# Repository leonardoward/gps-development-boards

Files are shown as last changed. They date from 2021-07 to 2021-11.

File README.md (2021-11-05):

# GPS Development Board - ANTENOVA M20050-1 and ATGM332D-5N31 #

<p align="center">
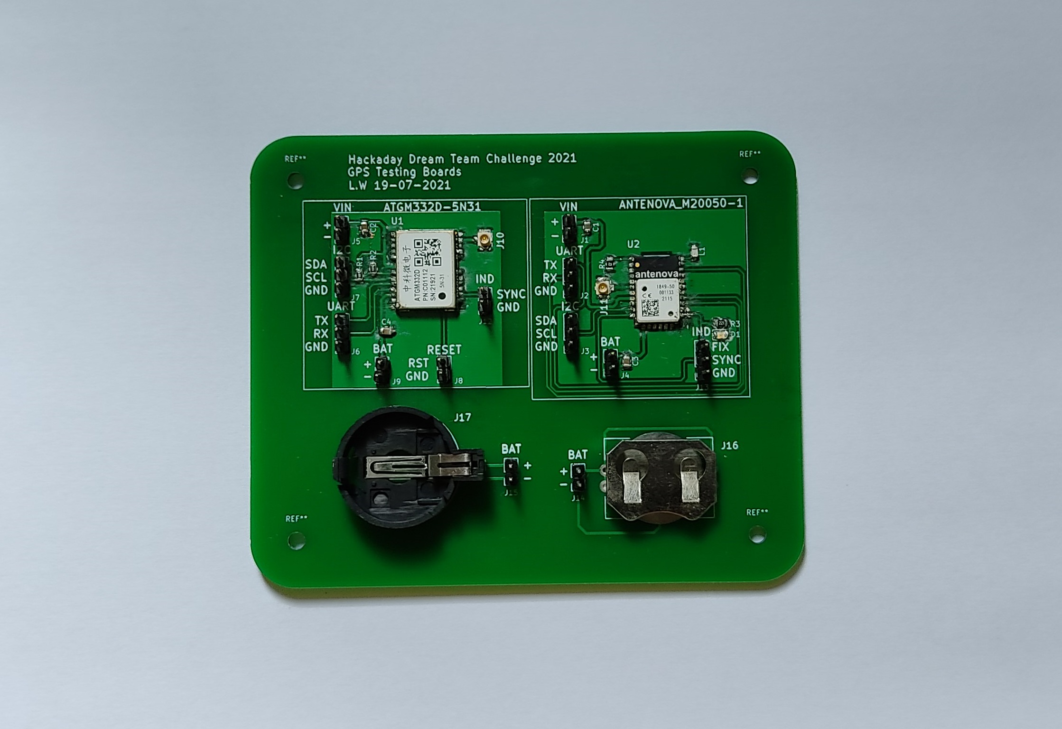
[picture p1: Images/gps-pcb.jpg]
  
</p>

This repository contains the design of a development board for the [ANTENOVA M20050-1](https://www.digikey.com/en/products/detail/antenova/M20050-1/7931495) and the [ATGM332D-5N31](https://lcsc.com/product-detail/Satellite-Positioning-Modules_ZHONGKEWEI-ATGM332D-5N31_C128659.html). The PCB was designed using KiCad.

## Schematic for the ANTENOVA M20050-1 ##

<p align="center">
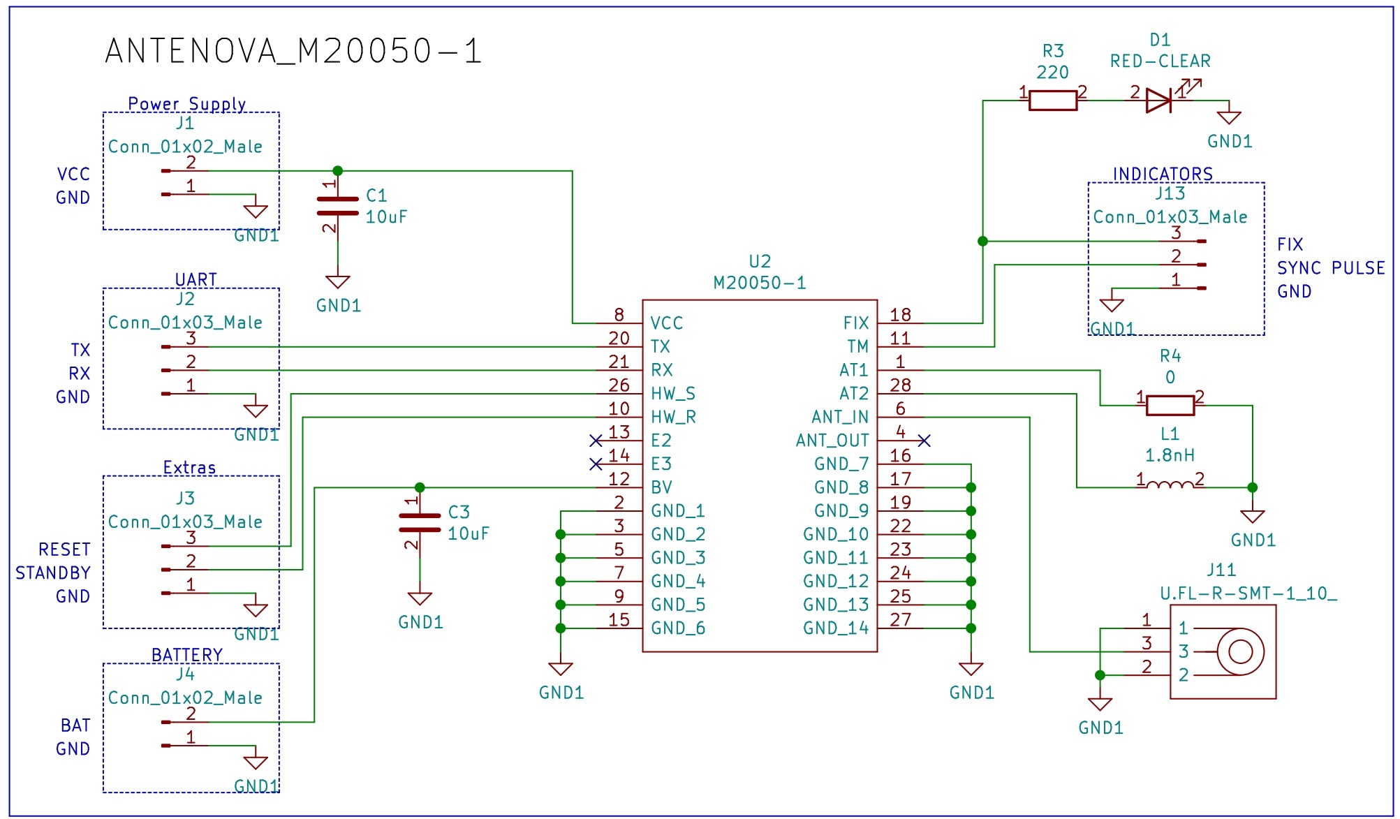
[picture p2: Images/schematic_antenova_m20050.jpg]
  
</p>

## Schematic for the ATGM332D-5N31 ##

<p align="center">
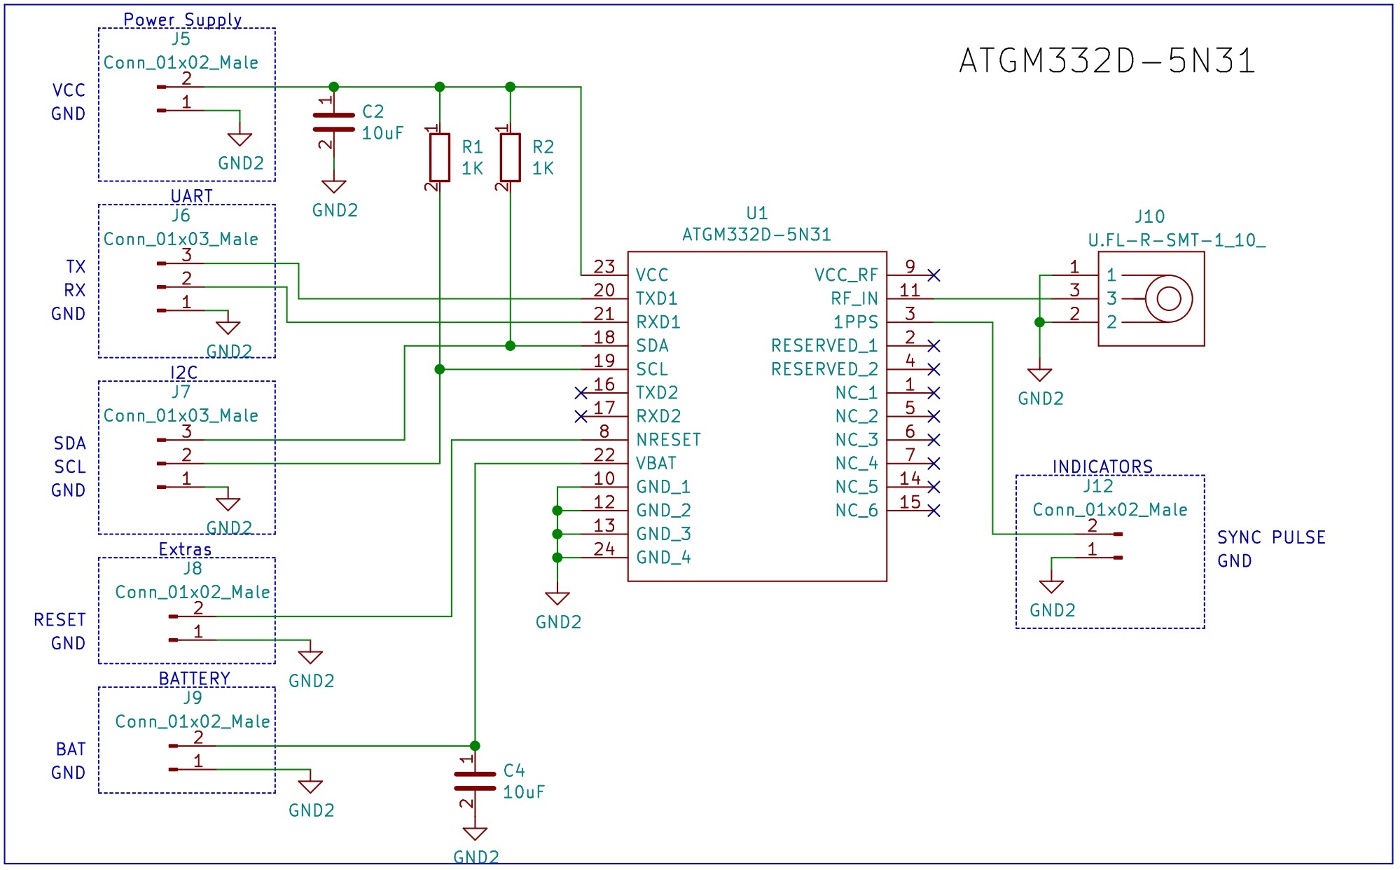
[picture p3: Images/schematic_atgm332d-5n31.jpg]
  
</p>

## Additional Coin Battery Holders ##

<p align="center">
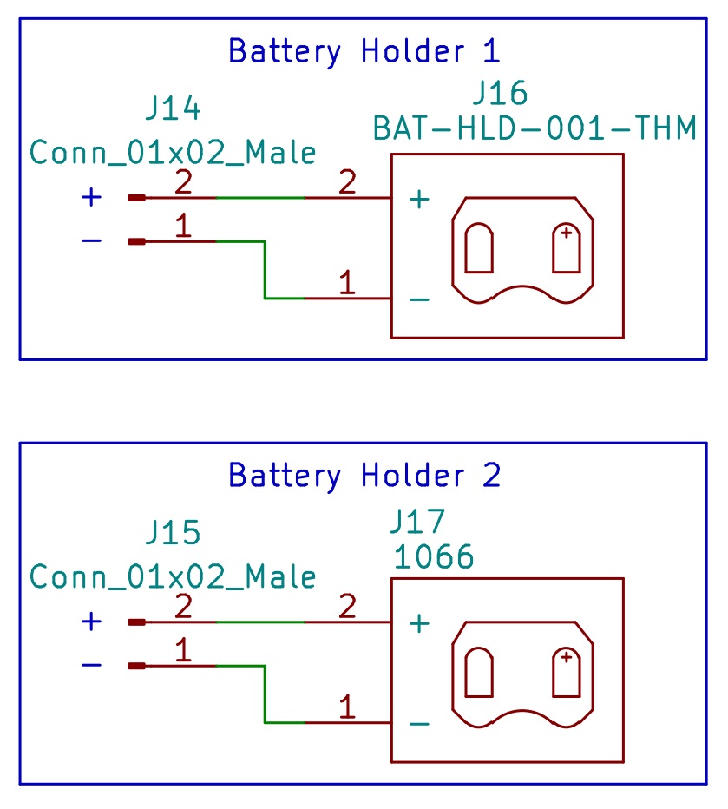
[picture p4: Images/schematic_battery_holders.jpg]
  
</p>

## Bill of Materials ##

| Reference | Quantity |
| --- | --- |
| [10 µF ±10% 6.3V Ceramic Capacitor X5R 0805 (2012 Metric)](https://www.digikey.com/en/products/detail/samsung-electro-mechanics/CL21A106KQCLNNC/3888062)  | 4 |
| [Red 630nm LED Indication - Discrete 1.9V 0805 (2012 Metric)](https://www.digikey.com/en/products/detail/w%C3%BCrth-elektronik/150080SS75000/4489921)  | 1 |
| [U.FL (UMCC) Connector Receptacle, Male Pin 50Ohm Surface Mount Solder](https://www.digikey.com/en/products/detail/hirose-electric-co-ltd/U-FL-R-SMT-1-10/2391570) | 2 |
| [Battery Retainer Coin, 20.0mm 1 Cell PC Pin](https://www.digikey.com/en/products/detail/linx-technologies-inc/BAT-HLD-001-THM/3044009) | 1 |
| [Battery Holder (Open) Coin, 20.0mm 1 Cell PC Pin](https://www.digikey.com/en/products/detail/keystone-electronics/1066/303562) | 1 |
| [Unshielded Multilayer Inductor 100mOhm Max 0805 (2012 Metric)](https://www.digikey.com/en/products/detail/abracon-llc/AIMC-0805-1N8S-T/2662915) | 1 |
| [1K ±1% 0.125W, 1/8W Chip Resistor 0805 (2012 Metric) Automotive AEC-Q200 Thick Film](https://www.digikey.com/en/products/detail/panasonic-electronic-components/ERJ-6ENF1001V/111281) | 2 |
| [220 Ohms ±5% 0.125W, 1/8W Chip Resistor 0805 (2012 Metric) Moisture Resistant Thick Film](https://www.digikey.com/en/products/detail/yageo/RC0805JR-07220RL/728283) | 1 |
| [0 Ohms Jumper 0.125W, 1/8W Chip Resistor 0805 (2012 Metric) Moisture Resistant Thick Film](https://www.digikey.com/en/products/detail/yageo/RC0805JR-070RL/728216) | 1 |
| [ATGM332D-5N31 GNSS Series GPS+BDS 12.2x16x2.4mm Satellite Positioning Modules ROHS](https://lcsc.com/product-detail/Satellite-Positioning-Modules_ZHONGKEWEI-ATGM332D-5N31_C128659.html) | 1 |
| [Antenova M20050-1 series RF Receiver GPS 1.575GHz -165dBm - On-Board, Trace Module](https://www.digikey.com/en/products/detail/antenova/M20050-1/7931495) | 1 |
| [Conn Header 40POS 2.54](https://www.digikey.com/en/products/detail/3m/2340-6111TG/1237275) | 1 |

## 3D Model ##

<p align="center">
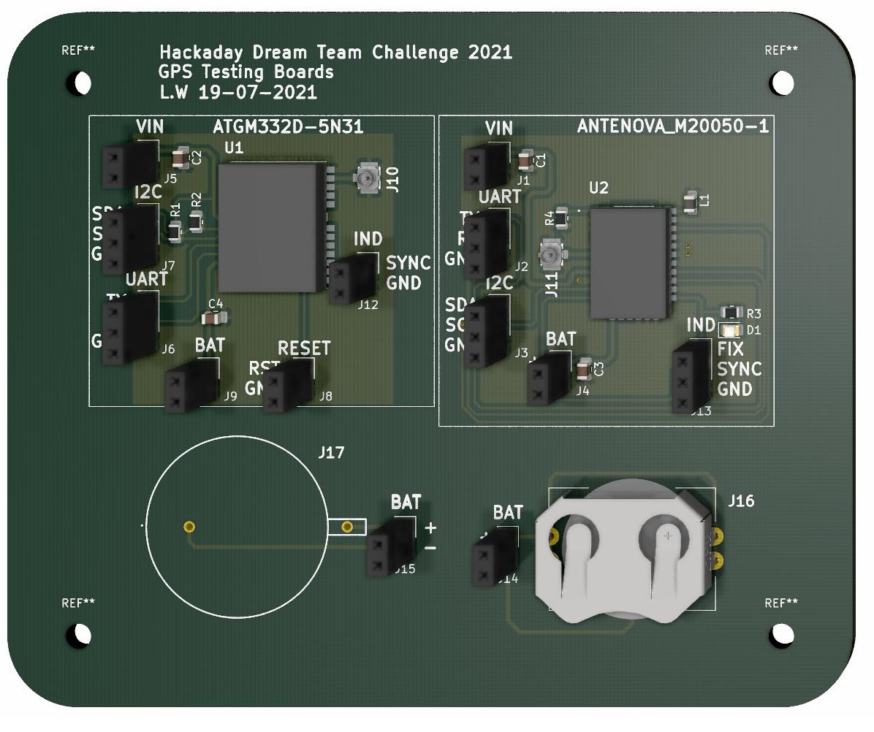
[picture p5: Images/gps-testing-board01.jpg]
  
</p>

<p align="center">
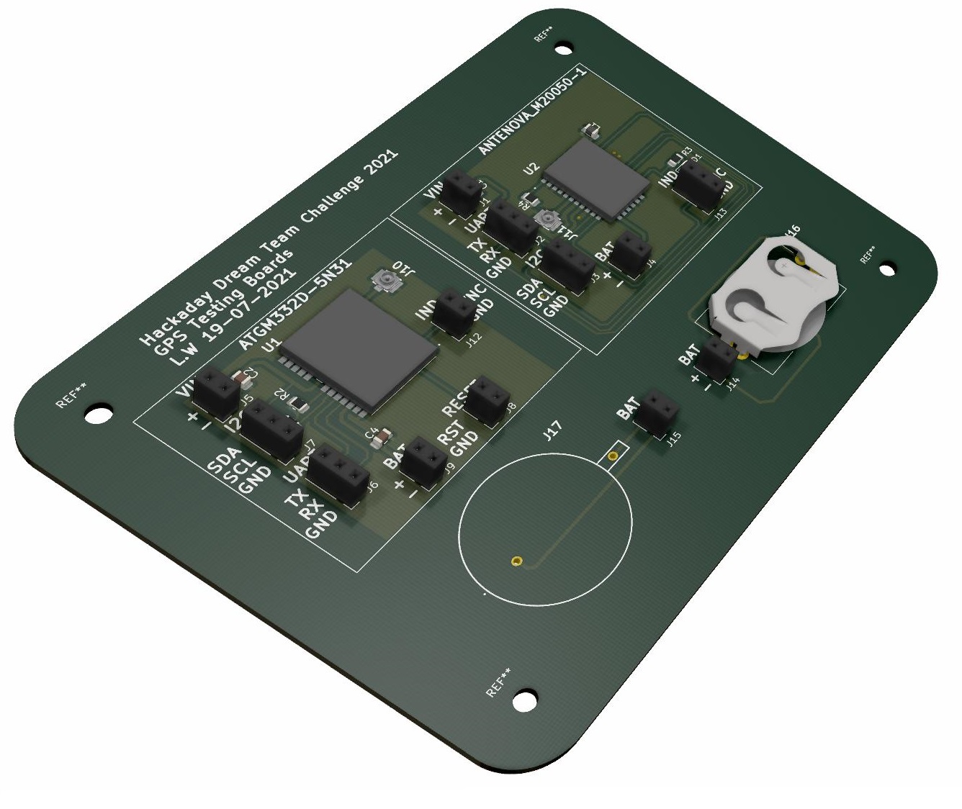
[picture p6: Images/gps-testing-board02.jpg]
  
</p>

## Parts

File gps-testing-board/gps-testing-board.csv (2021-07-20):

Source: | C:\Ext\gps-development-boards\gps-testing-board\gps-testing-board.sch
Date: | 7/19/2021 5:20:29 PM
Tool: | Eeschema (5.1.10)-1
Generator: | C:\Program Files\KiCad\bin\scripting\plugins/bom_csv_grouped_by_value.py
Component Count: | 29
Individual Components:
Item | Qty | Reference(s) | Value | LibPart | Footprint | Datasheet | Arrow Part Number | Arrow Price/Stock | Description | Height | LCSC | Manufacturer | Manufacturer Name | Manufacturer Part Number | Manufacturer_Name | Manufacturer_Part_Number | Mouser Part Number | Mouser Price/Stock | Supplier 1 | Supplier 2 | Supplier Part Number 1 | Supplier Part Number 2
 |  | C1 | 10uF | C-10uF-0805:10uF | Capacitor_SMD:C_0805_2012Metric |  |  |  |  |  |  | Samsung Electro-Mechanics |  | CL21A106KQCLNNC |  |  |  |  | Digi-Key |  | 1276-2404-1-ND
 |  | C2 | 10uF | C-10uF-0805:10uF | Capacitor_SMD:C_0805_2012Metric |  |  |  |  |  |  | Samsung Electro-Mechanics |  | CL21A106KQCLNNC |  |  |  |  | Digi-Key |  | 1276-2404-1-ND
 |  | C3 | 10uF | C-10uF-0805:10uF | Capacitor_SMD:C_0805_2012Metric |  |  |  |  |  |  | Samsung Electro-Mechanics |  | CL21A106KQCLNNC |  |  |  |  | Digi-Key |  | 1276-2404-1-ND
 |  | C4 | 10uF | C-10uF-0805:10uF | Capacitor_SMD:C_0805_2012Metric |  |  |  |  |  |  | Samsung Electro-Mechanics |  | CL21A106KQCLNNC |  |  |  |  | Digi-Key |  | 1276-2404-1-ND
 |  | D1 | RED-CLEAR | LED-RED-CLEAR-0805:RED-CLEAR | LED_SMD:LED_0805_2012Metric | https://www.we-online.de/katalog/datasheet/150080SS75000.pdf |  |  |  |  |  | Würth Elektronik |  | 150080SS75000 |  |  |  |  | Digi-Key |  | 732-4985-1-ND
 |  | J1 | Conn_01x02_Male | Connector:Conn_01x02_Male | Connector_PinSocket_2.54mm:PinSocket_1x02_P2.54mm_Vertical | ~
 |  | J2 | Conn_01x03_Male | Connector:Conn_01x03_Male | Connector_PinSocket_2.54mm:PinSocket_1x03_P2.54mm_Vertical | ~
 |  | J3 | Conn_01x03_Male | Connector:Conn_01x03_Male | Connector_PinSocket_2.54mm:PinSocket_1x03_P2.54mm_Vertical | ~
 |  | J4 | Conn_01x02_Male | Connector:Conn_01x02_Male | Connector_PinSocket_2.54mm:PinSocket_1x02_P2.54mm_Vertical | ~
 |  | J5 | Conn_01x02_Male | Connector:Conn_01x02_Male | Connector_PinSocket_2.54mm:PinSocket_1x02_P2.54mm_Vertical | ~
 |  | J6 | Conn_01x03_Male | Connector:Conn_01x03_Male | Connector_PinSocket_2.54mm:PinSocket_1x03_P2.54mm_Vertical | ~
 |  | J7 | Conn_01x03_Male | Connector:Conn_01x03_Male | Connector_PinSocket_2.54mm:PinSocket_1x03_P2.54mm_Vertical | ~
 |  | J8 | Conn_01x02_Male | Connector:Conn_01x02_Male | Connector_PinSocket_2.54mm:PinSocket_1x02_P2.54mm_Vertical | ~
 |  | J9 | Conn_01x02_Male | Connector:Conn_01x02_Male | Connector_PinSocket_2.54mm:PinSocket_1x02_P2.54mm_Vertical | ~
 |  | J10 | U.FL-R-SMT-1_10_ | U.FL-R-SMT-1_10_:U.FL-R-SMT-1_10_ | U.FL-R-SMT-1(10):U.FL-R-SMT-1_10_ | https://www.hirose.com/product/document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 | U.FL-R-SMT-1(10) | https://www.arrow.com/en/products/u.fl-r-smt-1-10/hirose-electric | UFL SMT PCB receptable,DC-6GHz Hirose Straight 50 Surface Mount UFL Connector, Receptacle, Solder Termination Coaxial |  |  |  | Hirose | U.FL-R-SMT-1(10) | Hirose | U.FL-R-SMT-1(10) | 798-U.FL-R-SMT-110 | https://www.mouser.co.uk/ProductDetail/Hirose-Connector/UFL-R-SMT-110?qs=kL1ClTr6oBoOdtqlGQpQrQ%3D%3D | Digi-Key | Mouser | H11891CT-ND | 798-U.FL-R-SMT-110
 |  | J11 | U.FL-R-SMT-1_10_ | U.FL-R-SMT-1_10_:U.FL-R-SMT-1_10_ | U.FL-R-SMT-1(10):U.FL-R-SMT-1_10_ | https://www.hirose.com/product/document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 | U.FL-R-SMT-1(10) | https://www.arrow.com/en/products/u.fl-r-smt-1-10/hirose-electric | UFL SMT PCB receptable,DC-6GHz Hirose Straight 50 Surface Mount UFL Connector, Receptacle, Solder Termination Coaxial |  |  |  | Hirose | U.FL-R-SMT-1(10) | Hirose | U.FL-R-SMT-1(10) | 798-U.FL-R-SMT-110 | https://www.mouser.co.uk/ProductDetail/Hirose-Connector/UFL-R-SMT-110?qs=kL1ClTr6oBoOdtqlGQpQrQ%3D%3D | Digi-Key | Mouser | H11891CT-ND | 798-U.FL-R-SMT-110
 |  | J12 | Conn_01x02_Male | Connector:Conn_01x02_Male | Connector_PinSocket_2.54mm:PinSocket_1x02_P2.54mm_Vertical | ~
 |  | J13 | Conn_01x03_Male | Connector:Conn_01x03_Male | Connector_PinSocket_2.54mm:PinSocket_1x03_P2.54mm_Vertical | ~
 |  | J14 | Conn_01x02_Male | Connector:Conn_01x02_Male | Connector_PinSocket_2.54mm:PinSocket_1x02_P2.54mm_Vertical | ~
 |  | J15 | Conn_01x02_Male | Connector:Conn_01x02_Male | Connector_PinSocket_2.54mm:PinSocket_1x02_P2.54mm_Vertical | ~
 |  | J16 | BAT-HLD-001-THM | BAT-HLD-001-THM:BAT-HLD-001-THM | BAT-HLD-001-THM:BATHLD001THM | http://www.mouser.com/datasheet/2/238/BAT-HLD-001-THM Diagram-1175214.pdf |  |  | Coin Cell Battery Holders Bat Hld CR2032/2025 Through-hole Mount | 4.2 |  |  |  |  | Linx Technologies | BAT-HLD-001-THM |  |  | Digi-Key | Mouser | BAT-HLD-001-THM-ND | 712-BAT-HLD-001-THM
 |  | J17 | 1066 | BAT-1066:1066 | BAT-1066:BAT-1066 | http://keyelco.com/userAssets/file/M65p5.pdf |  |  | KEYSTONE - 1066.. - Battery Holder, Coin Cell - 20mm x 1, Through Hole | 9.85 |  |  |  |  | Keystone Electronics | 1066 |  |  | Digi-Key | Mouser | 36-1066-ND | 534-1066
 |  | L1 | 1.8nH | L-1.8nH-0805:1.8nH | Inductor_SMD:L_0805_2012Metric | https://abracon.com/Magnetics/new/AIMC-0805.pdf |  |  |  |  |  | Abracon LLC |  | AIMC-0805-1N8S-T |  |  |  |  | Digi-Key |  | 535-11559-1-ND
 |  | R1 | 1K | R-1K-0805:1K | Resistor_SMD:R_0805_2012Metric | https://industrial.panasonic.com/cdbs/www-data/pdf/RDA0000/AOA0000C304.pdf |  |  |  |  |  | Panasonic Electronic Components |  | ERJ-6ENF1001V |  |  |  |  | Digi-Key |  | P1.00KCCT-ND
 |  | R2 | 1K | R-1K-0805:1K | Resistor_SMD:R_0805_2012Metric | https://industrial.panasonic.com/cdbs/www-data/pdf/RDA0000/AOA0000C304.pdf |  |  |  |  |  | Panasonic Electronic Components |  | ERJ-6ENF1001V |  |  |  |  | Digi-Key |  | P1.00KCCT-ND
 |  | R3 | 220 | R-220-0805:220 | Resistor_SMD:R_0805_2012Metric | https://www.yageo.com/upload/media/product/productsearch/datasheet/rchip/PYu-RC_Group_51_RoHS_L_11.pdf |  |  |  |  |  | Yageo |  | RC0805JR-07220RL |  |  |  |  | Digi-Key |  | 311-220ARCT-ND
 |  | R4 | 0 | R-0-0805:0 | Resistor_SMD:R_0805_2012Metric | https://www.yageo.com/upload/media/product/productsearch/datasheet/rchip/PYu-RC_Group_51_RoHS_L_11.pdf |  |  |  |  |  | Yageo |  | RC0805JR-070RL |  |  |  |  | Digi-Key |  | 311-0.0ARCT-ND
 |  | U1 | ATGM332D-5N31 | ATGM332D-5N31:ATGM332D-5N31 | ATGM332D-5N31:ATGM332D5N31 | https://datasheet.lcsc.com/szlcsc/ZHONGKEWEI-ATGM332D-5N31_C128659.pdf |  |  | Communication Modules/GNSS Modules 12.2x16x2.4mm | 2.6 | C128659 |  |  |  | ZHONGKEWEI | ATGM332D-5N31
 |  | U2 | M20050-1 | M20050-1:M20050-1 | M20050-1:M200501 | https://www.mouser.com/datasheet/2/23/antenova_M20050-1-1279284.pdf |  |  | Antennas GPS/GNSS RADIONOVA RF Module MTK chipset | 2 |  |  |  |  | Antenova | M20050-1 |  |  | Digi-Key | Mouser | 627-1100-1-ND | 237-M20050-1
Collated Components:
Item | Qty | Reference(s) | Value | LibPart | Footprint | Datasheet | Arrow Part Number | Arrow Price/Stock | Description | Height | LCSC | Manufacturer | Manufacturer Name | Manufacturer Part Number | Manufacturer_Name | Manufacturer_Part_Number | Mouser Part Number | Mouser Price/Stock | Supplier 1 | Supplier 2 | Supplier Part Number 1 | Supplier Part Number 2
1 | 4 | C1, C2, C3, C4 | 10uF | C-10uF-0805:10uF | Capacitor_SMD:C_0805_2012Metric |  |  |  |  |  |  | Samsung Electro-Mechanics |  | CL21A106KQCLNNC |  |  |  |  | Digi-Key |  | 1276-2404-1-ND
2 | 1 | D1 | RED-CLEAR | LED-RED-CLEAR-0805:RED-CLEAR | LED_SMD:LED_0805_2012Metric | https://www.we-online.de/katalog/datasheet/150080SS75000.pdf |  |  |  |  |  | Würth Elektronik |  | 150080SS75000 |  |  |  |  | Digi-Key |  | 732-4985-1-ND
3 | 8 | J1, J4, J5, J8, J9, J12, J14, J15 | Conn_01x02_Male | Connector:Conn_01x02_Male | Connector_PinSocket_2.54mm:PinSocket_1x02_P2.54mm_Vertical | ~
4 | 5 | J2, J3, J6, J7, J13 | Conn_01x03_Male | Connector:Conn_01x03_Male | Connector_PinSocket_2.54mm:PinSocket_1x03_P2.54mm_Vertical | ~
5 | 2 | J10, J11 | U.FL-R-SMT-1_10_ | U.FL-R-SMT-1_10_:U.FL-R-SMT-1_10_ | U.FL-R-SMT-1(10):U.FL-R-SMT-1_10_ | https://www.hirose.com/product/document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 | U.FL-R-SMT-1(10) | https://www.arrow.com/en/products/u.fl-r-smt-1-10/hirose-electric | UFL SMT PCB receptable,DC-6GHz Hirose Straight 50 Surface Mount UFL Connector, Receptacle, Solder Termination Coaxial |  |  |  | Hirose | U.FL-R-SMT-1(10) | Hirose | U.FL-R-SMT-1(10) | 798-U.FL-R-SMT-110 | https://www.mouser.co.uk/ProductDetail/Hirose-Connector/UFL-R-SMT-110?qs=kL1ClTr6oBoOdtqlGQpQrQ%3D%3D | Digi-Key | Mouser | H11891CT-ND | 798-U.FL-R-SMT-110
6 | 1 | J16 | BAT-HLD-001-THM | BAT-HLD-001-THM:BAT-HLD-001-THM | BAT-HLD-001-THM:BATHLD001THM | http://www.mouser.com/datasheet/2/238/BAT-HLD-001-THM Diagram-1175214.pdf |  |  | Coin Cell Battery Holders Bat Hld CR2032/2025 Through-hole Mount | 4.2 |  |  |  |  | Linx Technologies | BAT-HLD-001-THM |  |  | Digi-Key | Mouser | BAT-HLD-001-THM-ND | 712-BAT-HLD-001-THM
7 | 1 | J17 | 1066 | BAT-1066:1066 | BAT-1066:BAT-1066 | http://keyelco.com/userAssets/file/M65p5.pdf |  |  | KEYSTONE - 1066.. - Battery Holder, Coin Cell - 20mm x 1, Through Hole | 9.85 |  |  |  |  | Keystone Electronics | 1066 |  |  | Digi-Key | Mouser | 36-1066-ND | 534-1066
8 | 1 | L1 | 1.8nH | L-1.8nH-0805:1.8nH | Inductor_SMD:L_0805_2012Metric | https://abracon.com/Magnetics/new/AIMC-0805.pdf |  |  |  |  |  | Abracon LLC |  | AIMC-0805-1N8S-T |  |  |  |  | Digi-Key |  | 535-11559-1-ND
9 | 2 | R1, R2 | 1K | R-1K-0805:1K | Resistor_SMD:R_0805_2012Metric | https://industrial.panasonic.com/cdbs/www-data/pdf/RDA0000/AOA0000C304.pdf |  |  |  |  |  | Panasonic Electronic Components |  | ERJ-6ENF1001V |  |  |  |  | Digi-Key |  | P1.00KCCT-ND
10 | 1 | R3 | 220 | R-220-0805:220 | Resistor_SMD:R_0805_2012Metric | https://www.yageo.com/upload/media/product/productsearch/datasheet/rchip/PYu-RC_Group_51_RoHS_L_11.pdf |  |  |  |  |  | Yageo |  | RC0805JR-07220RL |  |  |  |  | Digi-Key |  | 311-220ARCT-ND
11 | 1 | R4 | 0 | R-0-0805:0 | Resistor_SMD:R_0805_2012Metric | https://www.yageo.com/upload/media/product/productsearch/datasheet/rchip/PYu-RC_Group_51_RoHS_L_11.pdf |  |  |  |  |  | Yageo |  | RC0805JR-070RL |  |  |  |  | Digi-Key |  | 311-0.0ARCT-ND
12 | 1 | U1 | ATGM332D-5N31 | ATGM332D-5N31:ATGM332D-5N31 | ATGM332D-5N31:ATGM332D5N31 | https://datasheet.lcsc.com/szlcsc/ZHONGKEWEI-ATGM332D-5N31_C128659.pdf |  |  | Communication Modules/GNSS Modules 12.2x16x2.4mm | 2.6 | C128659 |  |  |  | ZHONGKEWEI | ATGM332D-5N31
13 | 1 | U2 | M20050-1 | M20050-1:M20050-1 | M20050-1:M200501 | https://www.mouser.com/datasheet/2/23/antenova_M20050-1-1279284.pdf |  |  | Antennas GPS/GNSS RADIONOVA RF Module MTK chipset | 2 |  |  |  |  | Antenova | M20050-1 |  |  | Digi-Key | Mouser | 627-1100-1-ND | 237-M20050-1

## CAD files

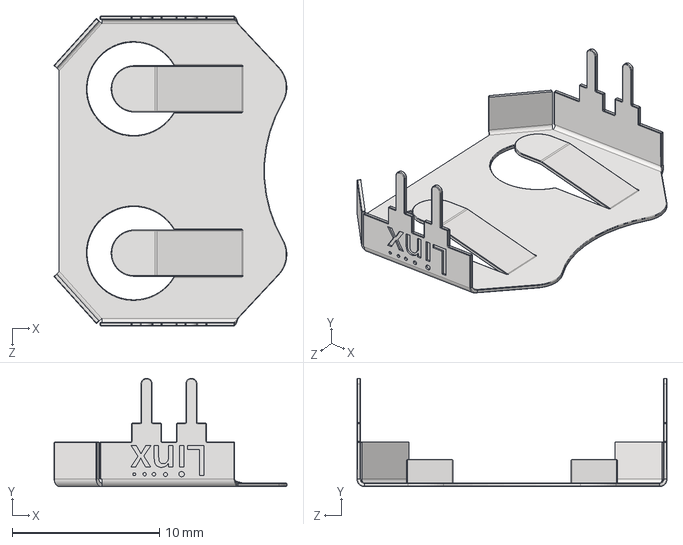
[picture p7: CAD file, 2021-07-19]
gps-testing-board/3D/BAT-HLD-001-THM.stp
15.8 x 7.37 x 21.1 mm

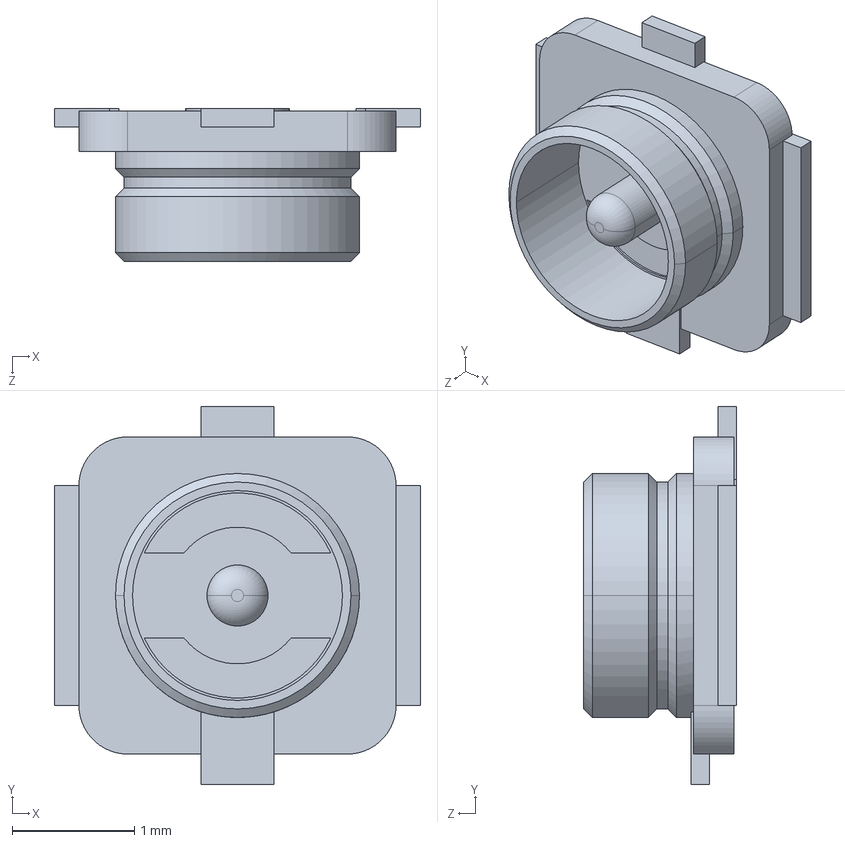
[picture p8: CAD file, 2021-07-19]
gps-testing-board/3D/U.FL-R-SMT-1_10_.stp
3.00 x 3.10 x 1.25 mm

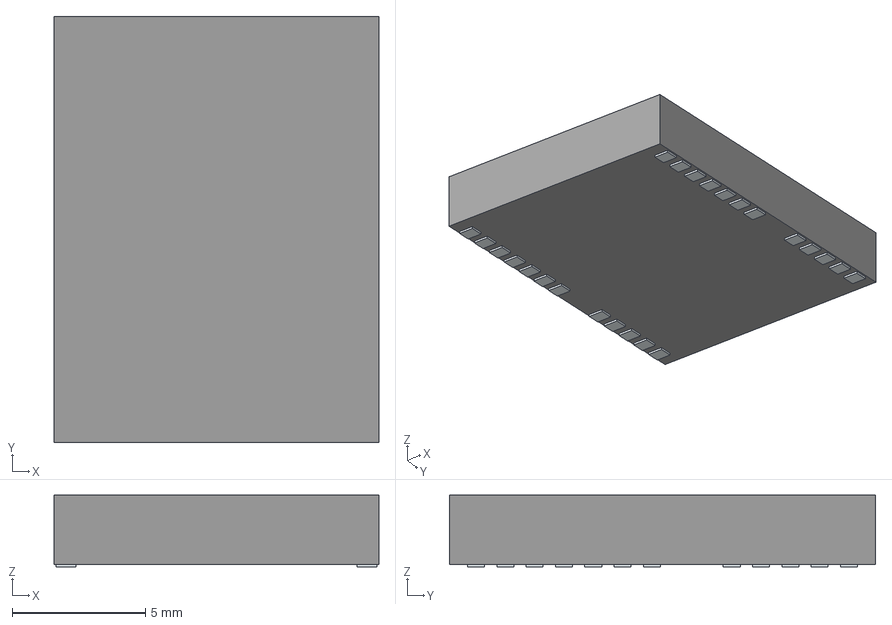
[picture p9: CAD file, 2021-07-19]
gps-testing-board/3D/ATGM332D-5N31.stp
12.2 x 16.0 x 2.70 mm
Pins

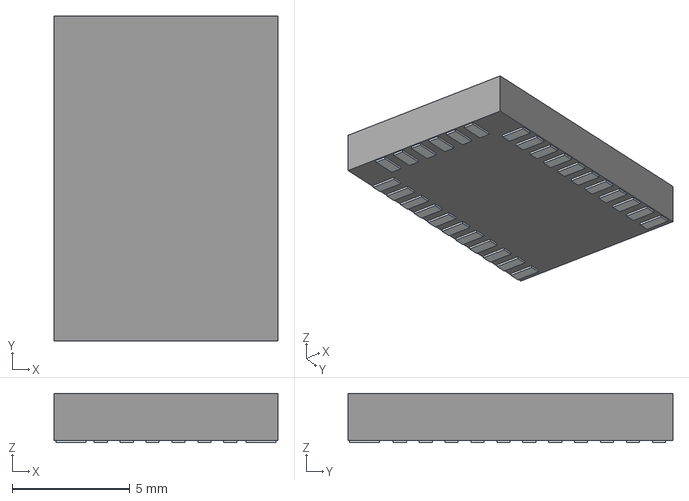
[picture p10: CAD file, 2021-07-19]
gps-testing-board/3D/M20050-1.stp
9.50 x 13.8 x 2.10 mm
Pins

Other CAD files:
gps-testing-board/3D/ATGM332D-5N31.stl
gps-testing-board/3D/M20050-1.stl

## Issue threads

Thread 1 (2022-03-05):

No GPS FIX

josullivan31, 2022-03-05:
Hello, using this schematic I was unable to get a GPS Fix. it would occasionally detect 2-7 GPS satellites but never long enough to get a fix. Would you be able to provide any insight as to why this is?

Thank you,

Jack

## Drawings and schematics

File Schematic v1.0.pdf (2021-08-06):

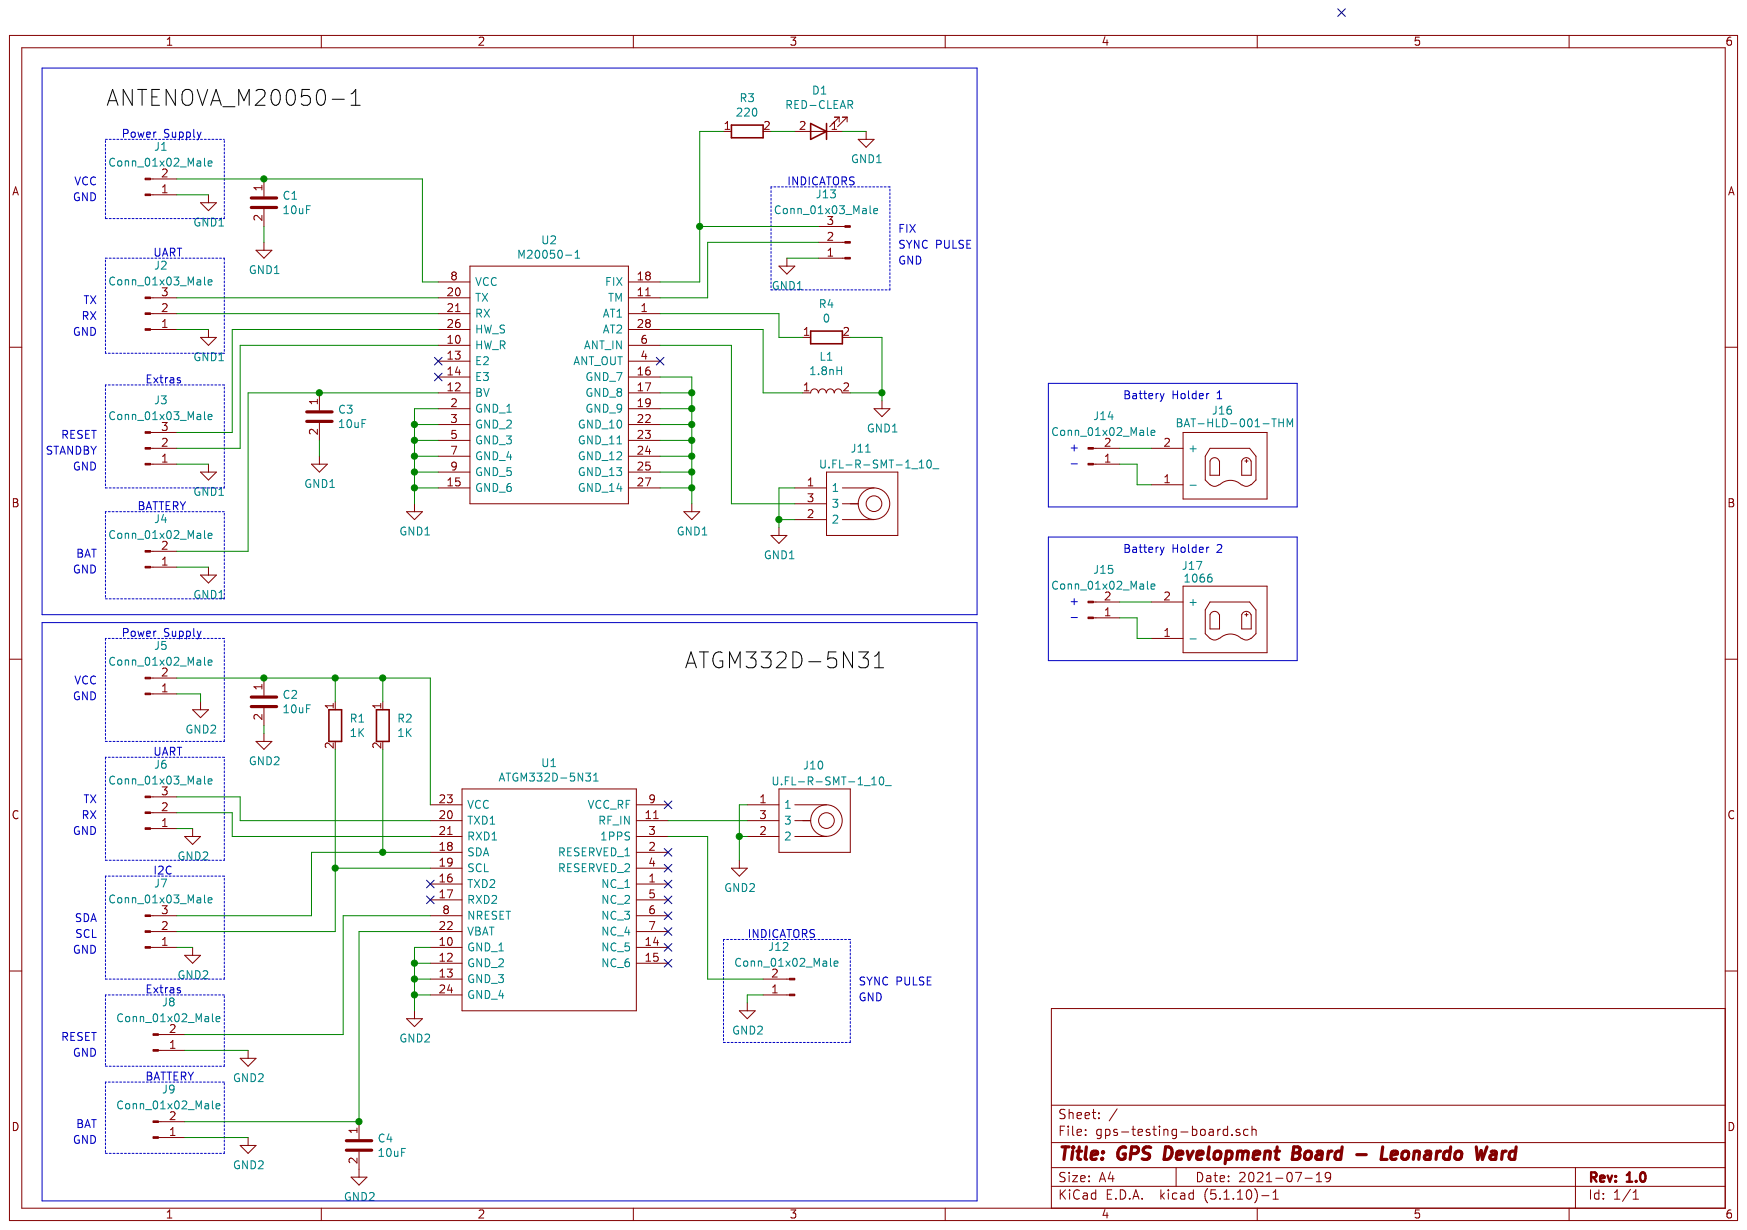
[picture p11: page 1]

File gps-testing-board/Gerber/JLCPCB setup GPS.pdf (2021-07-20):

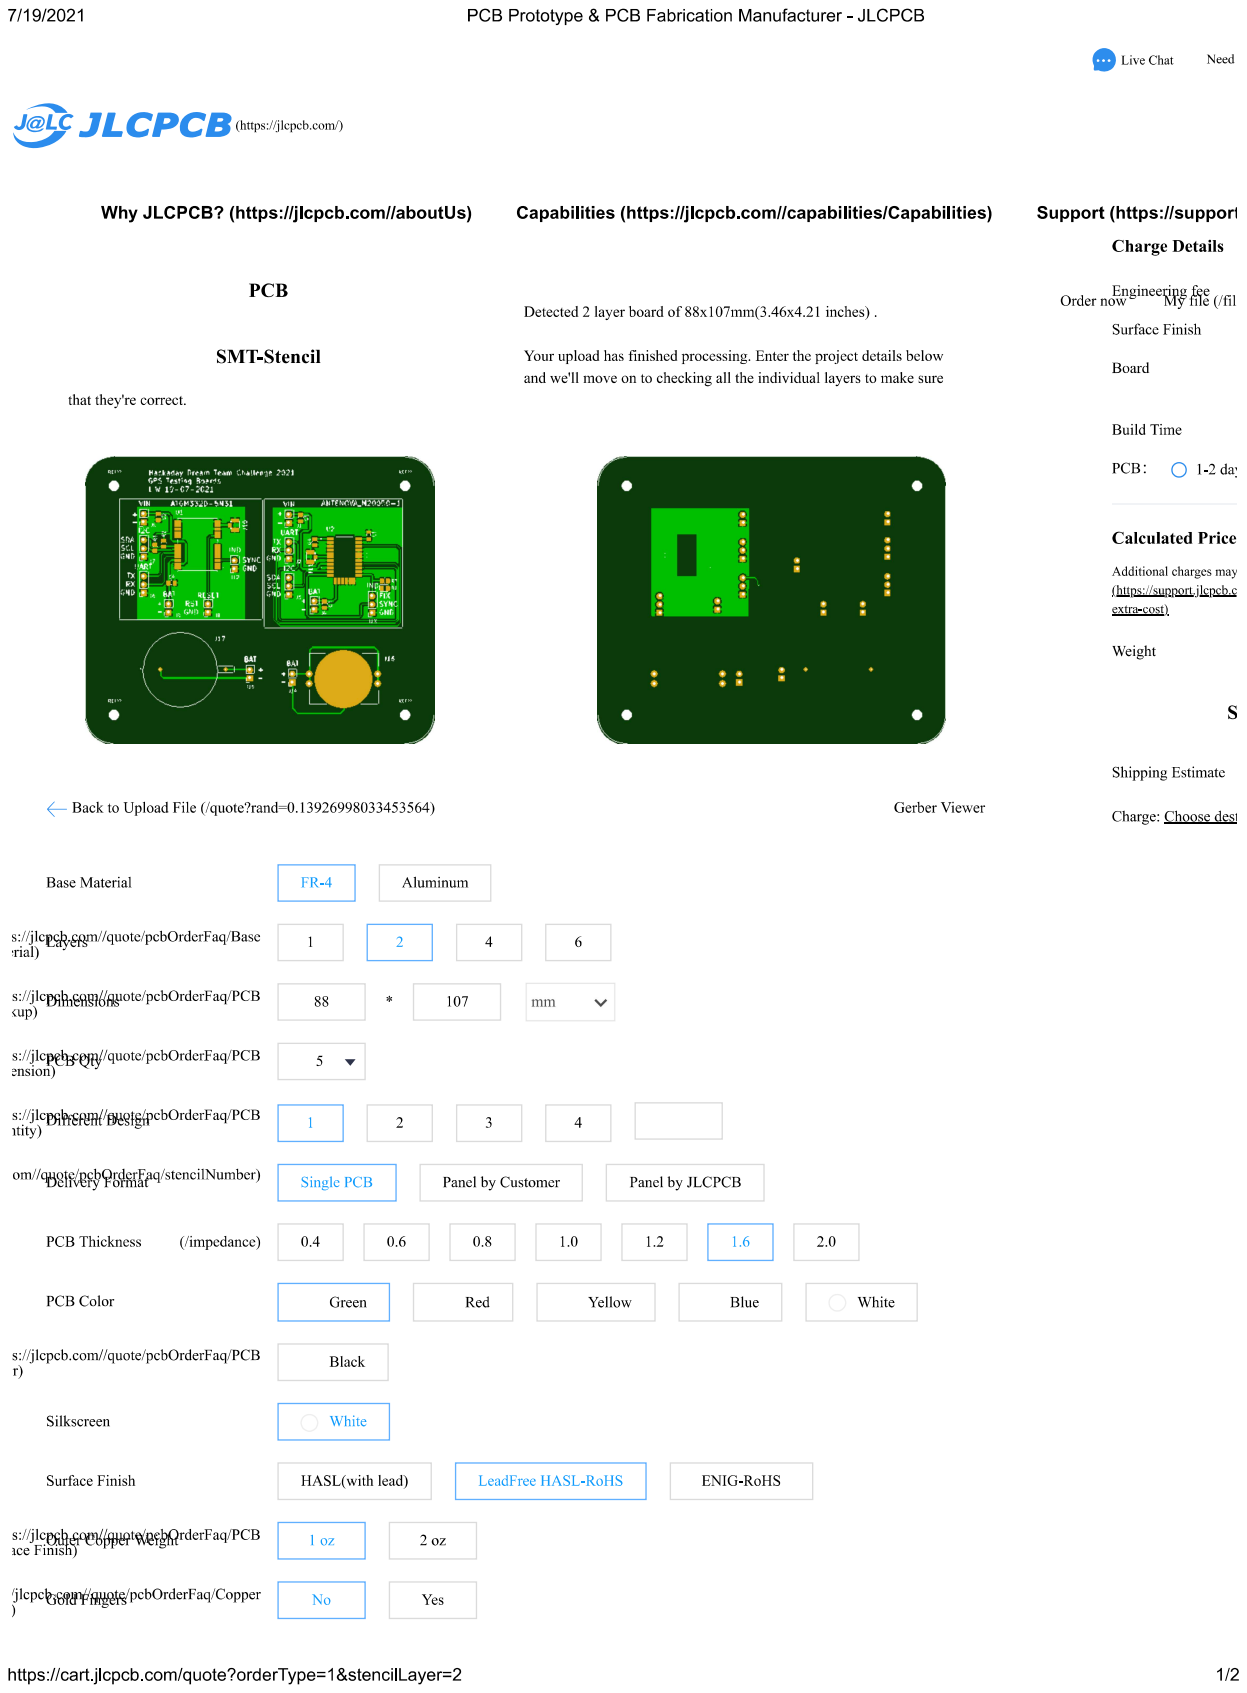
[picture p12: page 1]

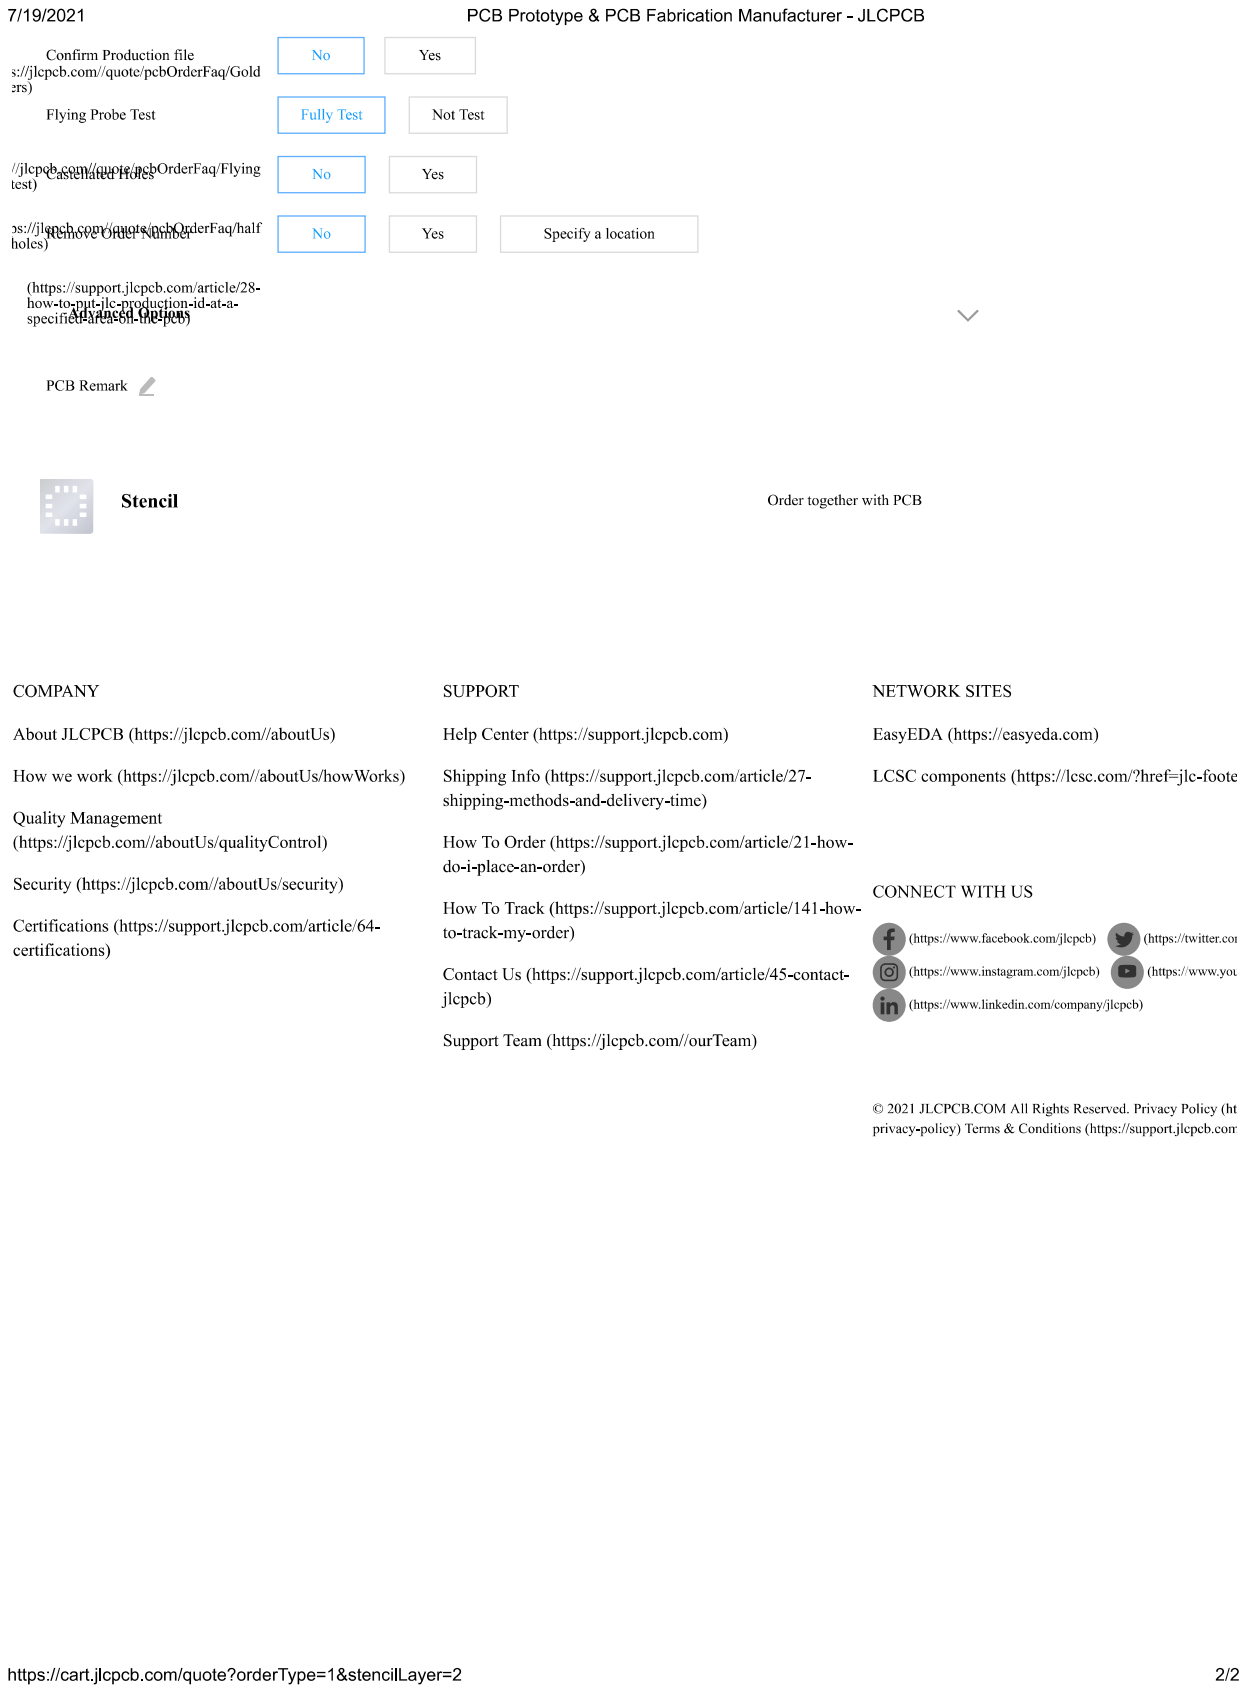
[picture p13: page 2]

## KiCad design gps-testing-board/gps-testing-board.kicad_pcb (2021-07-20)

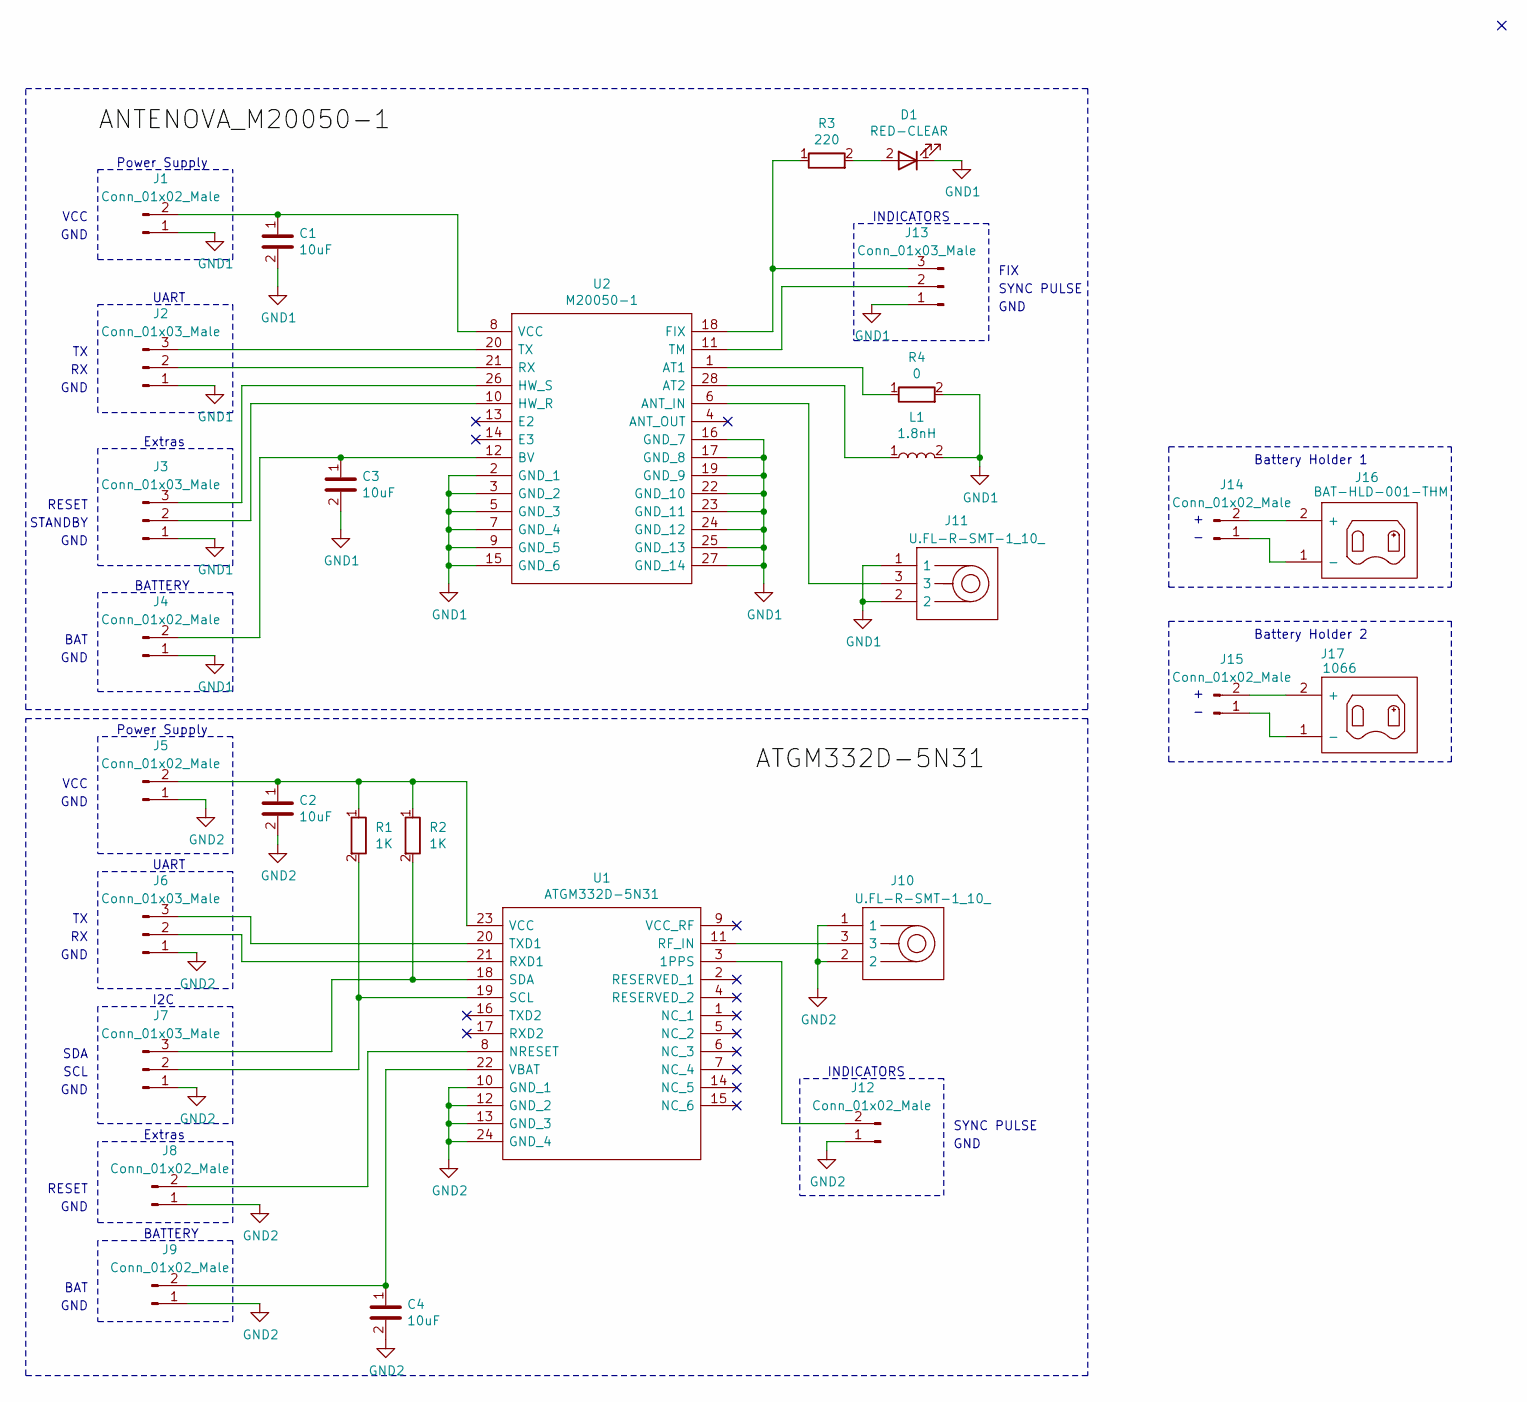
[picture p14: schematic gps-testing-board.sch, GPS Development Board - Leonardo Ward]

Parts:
C1, C2, C3, C4: 10uF; C_0805_2012Metric; Manufacturer Part Number CL21A106KQCLNNC
D1: RED-CLEAR; LED_0805_2012Metric; Manufacturer Part Number 150080SS75000
J1, J4, J5, J8, J9, J12, J14, J15: Conn_01x02_Male; PinSocket_1x02_P2.54mm_Vertical
J2, J3, J6, J7, J13: Conn_01x03_Male; PinSocket_1x03_P2.54mm_Vertical
J10, J11: U.FL-R-SMT-1_10_; Manufacturer_Part_Number U.FL-R-SMT-1(10); Mouser Part Number 798-U.FL-R-SMT-110
J16: BAT-HLD-001-THM; BATHLD001THM; Manufacturer_Part_Number BAT-HLD-001-THM
J17: 1066; BAT-1066; Manufacturer_Part_Number 1066
L1: 1.8nH; L_0805_2012Metric; Manufacturer Part Number AIMC-0805-1N8S-T
R1, R2: 1K; R_0805_2012Metric; Manufacturer Part Number ERJ-6ENF1001V
R3: 220; R_0805_2012Metric; Manufacturer Part Number RC0805JR-07220RL
R4: 0; R_0805_2012Metric; Manufacturer Part Number RC0805JR-070RL
U1: ATGM332D-5N31; ATGM332D5N31; Manufacturer_Part_Number ATGM332D-5N31; LCSC C128659
U2: M20050-1; M200501; Manufacturer_Part_Number M20050-1

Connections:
GND1: C1.2, C3.2, D1.1 (K), J1.1, J2.1, J3.1, J4.1, J11.1, J11.2, J13.1, L1.2, R4.2, U2.2 (GND_1), U2.3 (GND_2), U2.5 (GND_3), U2.7 (GND_4), U2.9 (GND_5), U2.15 (GND_6), U2.16 (GND_7), U2.17 (GND_8), U2.19 (GND_9), U2.22 (GND_10), U2.23 (GND_11), U2.24 (GND_12), U2.25 (GND_13), U2.27 (GND_14)
GND2: C2.2, C4.2, J5.1, J6.1, J7.1, J8.1, J9.1, J10.1, J10.2, J12.1, U1.10 (GND_1), U1.12 (GND_2), U1.13 (GND_3), U1.24 (GND_4)
unnamed: C1.1, J1.2, U2.8 (VCC)
unnamed: C2.1, J5.2, R1.1, R2.1, U1.23 (VCC)
unnamed: C3.1, J4.2, U2.12 (BV)
unnamed: C4.1, J9.2, U1.22 (VBAT)
unnamed: D1.2 (A), R3.2
unnamed: J2.2, U2.21 (RX)
unnamed: J2.3, U2.20 (TX)
unnamed: J3.2, U2.10 (HW_R)
unnamed: J3.3, U2.26 (HW_S)
unnamed: J6.2, U1.21 (RXD1)
unnamed: J6.3, U1.20 (TXD1)
unnamed: J7.2, R1.2, U1.19 (SCL)
unnamed: J7.3, R2.2, U1.18 (SDA)
unnamed: J8.2, U1.8 (NRESET)
unnamed: J10.3, U1.11 (RF_IN)
unnamed: J11.3, U2.6 (ANT_IN)
unnamed: J12.2, U1.3 (1PPS)
unnamed: J13.2, U2.11 (TM)
unnamed: J13.3, R3.1, U2.18 (FIX)
unnamed: J14.1, J16.1 (-)
unnamed: J14.2, J16.2 (+)
unnamed: J15.1, J17.1 (-)
unnamed: J15.2, J17.2 (+)
unnamed: L1.1, U2.28 (AT2)
unnamed: R4.1, U2.1 (AT1)

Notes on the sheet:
VCC
GND
UART
Power Supply
Extras
RESET
STANDBY
BATTERY
BAT
INDICATORS
FIX
SYNC PULSE
SDA
SCL
I2C
Battery Holder 1
Battery Holder 2

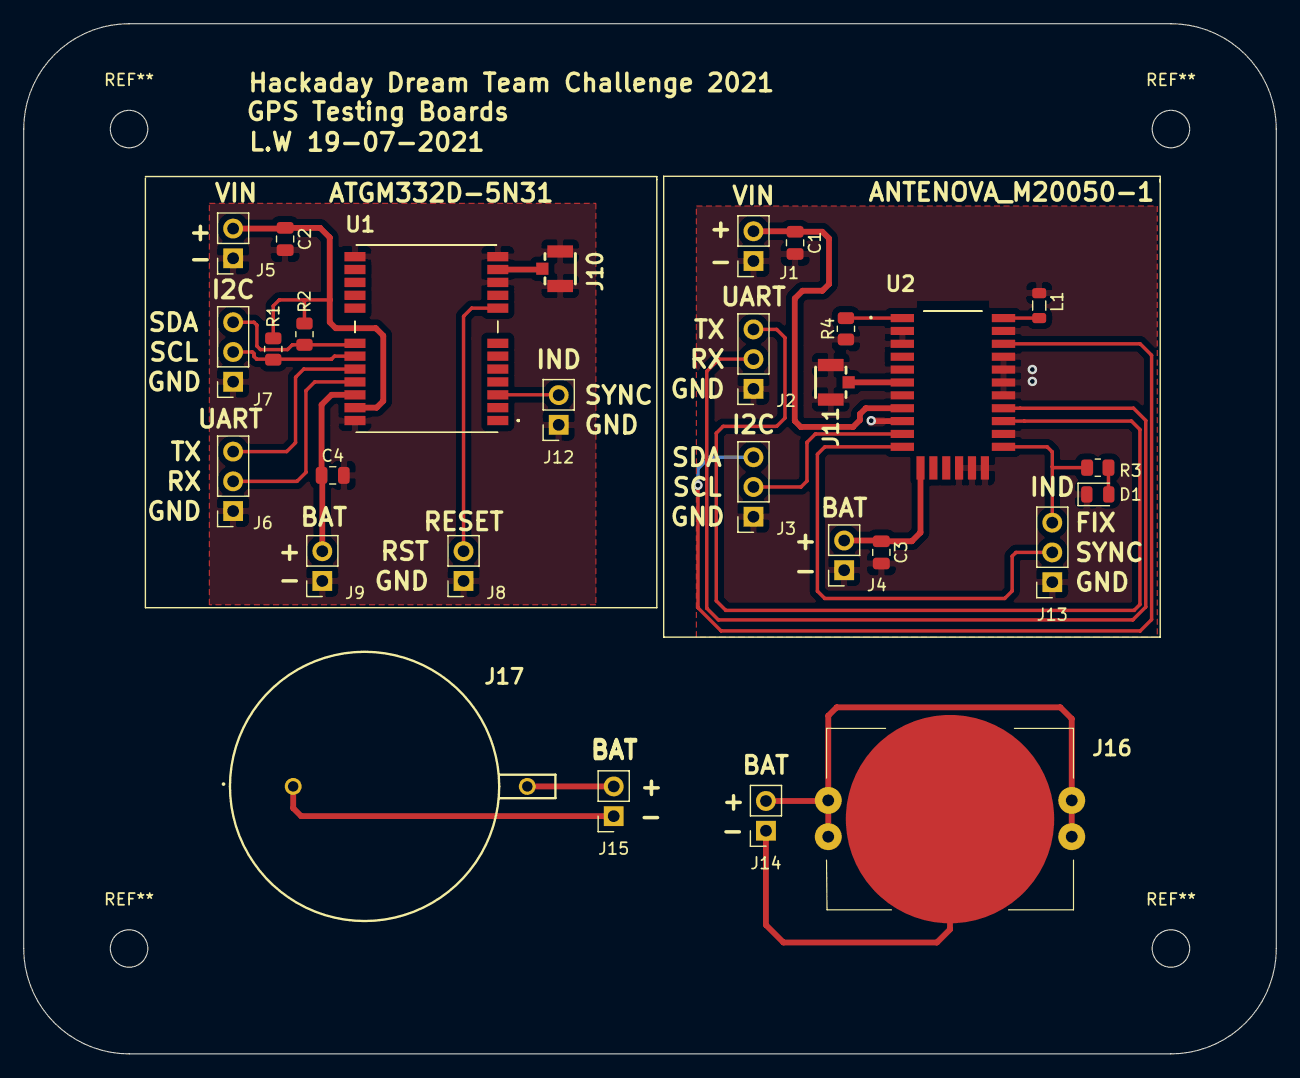
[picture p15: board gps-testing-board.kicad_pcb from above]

Board: 2 copper layers, 107.0 x 88.0 mm, 29 parts (0 on the bottom side), 27 nets.

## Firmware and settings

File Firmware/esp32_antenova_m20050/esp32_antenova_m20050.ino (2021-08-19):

//#include <NeoSWSerial.h>
#include <FuGPS.h>

#define RXD2 16
#define TXD2 17

//NeoSWSerial in(8, 9);
FuGPS fuGPS(Serial2);

bool gpsAlive = false;

void setup() {
   Serial.begin(115200);
   Serial.println("Antenova M20050");
   //in.begin(9600);
   Serial2.begin(9600, SERIAL_8N1, RXD2, TXD2);
   // fuGPS.sendCommand(FUGPS_PMTK_SET_NMEA_BAUDRATE_9600);
   // fuGPS.sendCommand(FUGPS_PMTK_SET_NMEA_UPDATERATE_1HZ);
   fuGPS.sendCommand(FUGPS_PMTK_API_SET_NMEA_OUTPUT_RMCGGA);
}
  
void loop() {
   // Valid NMEA message

   if (fuGPS.read())
   {
       byte tokenIdx = 0;
       while (const char * token = fuGPS.getField(tokenIdx++))
       {
           Serial.print("Token [" + String(tokenIdx) + "]: ");
           Serial.println(token);
       }
       Serial.println();
   }

   // Valid NMEA message
   /*
    if (fuGPS.read())
    {
        // We don't know, which message was came first (GGA or RMC).
        // Thats why some fields may be empty.

        gpsAlive = true;

        Serial.print("Quality: ");
        Serial.println(fuGPS.Quality);

        Serial.print("Satellites: ");
        Serial.println(fuGPS.Satellites);

        if (fuGPS.hasFix() == true)
        {
            // Data from GGA message
            Serial.print("Accuracy (HDOP): ");
            Serial.println(fuGPS.Accuracy);

            Serial.print("Altitude (above sea level): ");
            Serial.println(fuGPS.Altitude);

            // Data from GGA or RMC
            Serial.print("Location (decimal degrees): ");
            Serial.println("https://www.google.com/maps/search/?api=1&query=" + String(fuGPS.Latitude, 6) + "," + String(fuGPS.Longitude, 6));
        }
    }

    // Default is 10 seconds
    if (fuGPS.isAlive() == false)
    {
        if (gpsAlive == true)
        {
            gpsAlive = false;
            Serial.println("GPS module not responding with valid data.");
            Serial.println("Check wiring or restart.");
        }
    }
    delay(100);
    */
}

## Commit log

2021-07-15 Added schematic for Antenova M20050-1
    [gps-testing-board.kicad_pcb, gps-testing-board.sch]
2021-07-19 Added PCB and battery holders
    [gps-testing-board.sch]
2021-07-19 Added 3D models
    [ATGM332D-5N31.stl, ATGM332D-5N31.stp, BAT-HLD-001-THM.stp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]
2021-07-20 Added IDFv3 and Gerber
    [gps-testing-board-B_Cu.gbr, gps-testing-board-B_Mask.gbr, gps-testing-board-B_Paste.gbr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]
2021-08-06 Added Bill of Materials and images to README
2021-11-05 Added image of the PCB
